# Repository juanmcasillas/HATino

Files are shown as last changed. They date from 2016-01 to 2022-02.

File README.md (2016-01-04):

# HATino
Head tracking using ARDUINO and BLUETOOTH reusing code from HATIRE, using GY-521 breakout board (MPU-6050) and HC-05 breakout board for
bluetooth communications. The system is powered by standard AA-batteries, so it's a complete standalone solution.

This project is aimed to create a head tracking system based on code released by FuraX49 for the HATIRE plugin for OpenTRACK.

OpenTRACK is an OpenSource project focused on head tracking for MSWindows, Linux and Apple OSX. 
Manages multiple tracking sources and support multiple outputs. See https://github.com/opentrack/opentrack
for more details.

HATino provides a full solution (hardware and software) for a head tracking system based on arduino,
using bluetooth as comunication layer, in order to avoid "wires". HATino is implemented on an
ARDUINO MICRO, with a custom PCB Board, using GY-521 IMU breakout board for gyro information, and
HC-05 bluetooth breakout board for communications. The project includes both hardware (schematics,
pcb HOW-TO info) and software (ARDUINO custom firmware and modifications, Bluetooth layer) in order
to get a complete, OpenSource system. The software is based on FuraX49' code, and some of the 
examples on i2clib for arduino.

Libraries:

I2Cdev			https://github.com/jrowberg/i2cdevlib.git

Wire			(included)

SoftwareSerial	(included)

For information on installing libraries, see: http://arduino.cc/en/Guide/Libraries

Based on hatire source code (by FuraX49):

http://sourceforge.net/projects/hatire/files/ARDUINO/MPU6050/HAT_100.ino/download

LocalFile                       GIT
-----------------------------------------------------------------------------------------
HAT_gy521_wip_bt.ino            HATino.ino

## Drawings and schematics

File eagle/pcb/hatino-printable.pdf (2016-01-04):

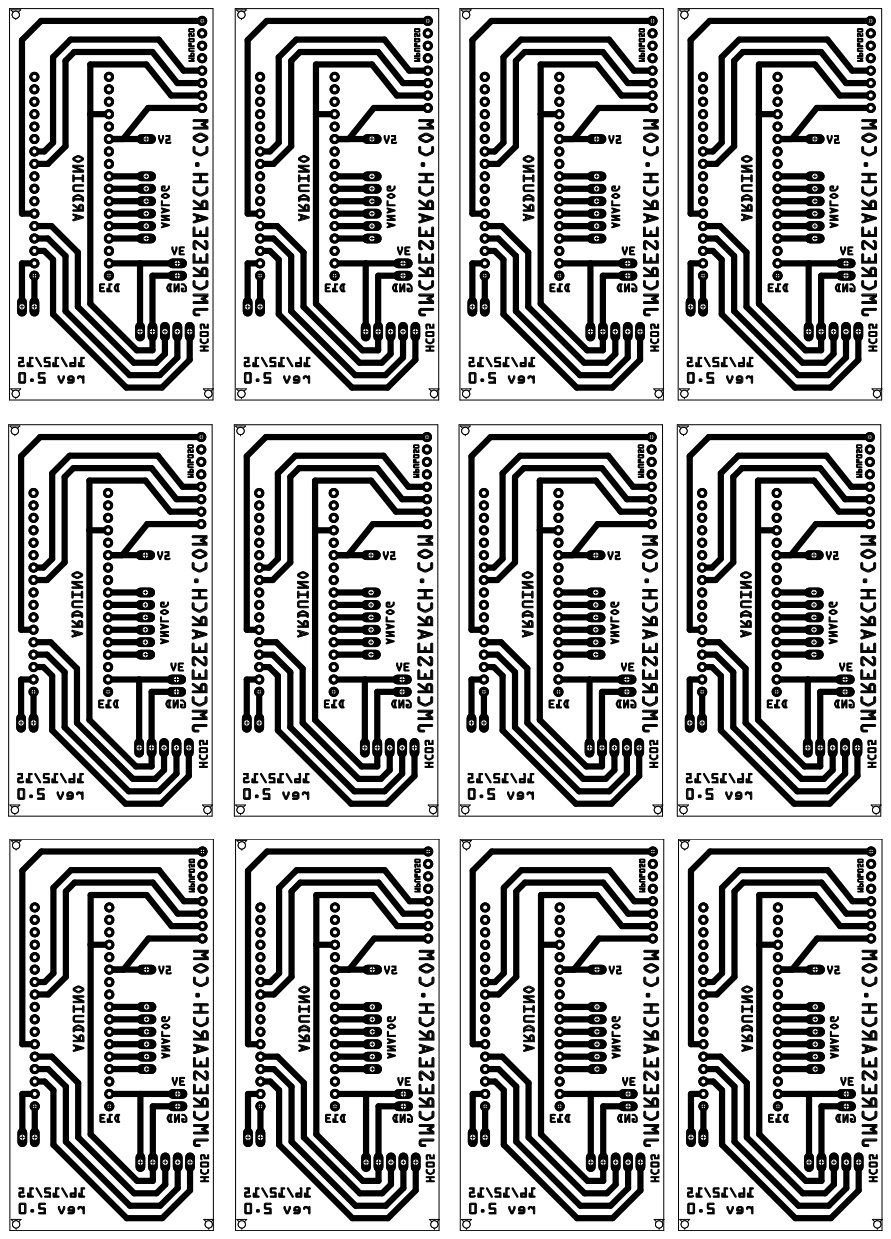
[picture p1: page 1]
JMCRESEARCH.COM; ANALOG; MPU6050; ARDUINO

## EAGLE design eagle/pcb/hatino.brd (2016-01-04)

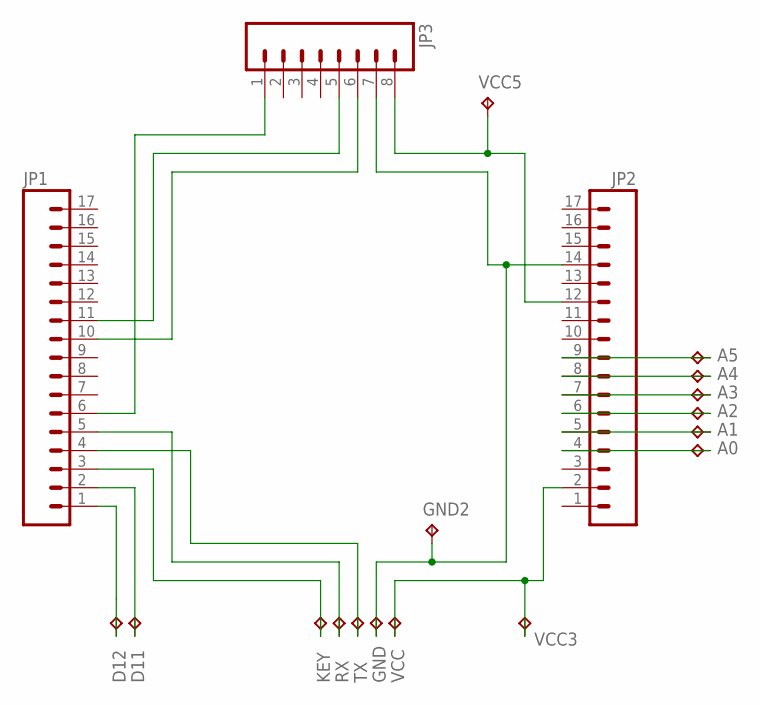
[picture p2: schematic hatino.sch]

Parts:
A0, A1, A2, A3, A4, A5: TPPAD1-13Y; P1-13Y
D11, D12: TPPAD1-13Y; P1-13Y
GND, GND2: TPPAD1-13Y; P1-13Y
JP1, JP2: M17; 1X17
JP3: M08; 1X08_ROUND
KEY: TPPAD1-13Y; P1-13Y
RX: TPPAD1-13Y; P1-13Y
TX: TPPAD1-13Y; P1-13Y
VCC, VCC3, VCC5: TPPAD1-13Y; P1-13Y

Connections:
unnamed: D12.TP, JP1.1
unnamed: JP2.2, VCC.TP, VCC3.TP
unnamed: D11.TP, JP1.2
unnamed: A0.TP, JP2.4
unnamed: A1.TP, JP2.5
unnamed: A2.TP, JP2.6
unnamed: A3.TP, JP2.7
unnamed: A4.TP, JP2.8
unnamed: A5.TP, JP2.9
unnamed: JP2.12, JP3.8, VCC5.TP
unnamed: GND.TP, GND2.TP, JP2.14, JP3.7
unnamed: JP1.5, RX.TP
unnamed: JP1.6, JP3.1
unnamed: JP1.4, TX.TP
unnamed: JP1.10, JP3.6
unnamed: JP1.11, JP3.5
unnamed: JP1.3, KEY.TP

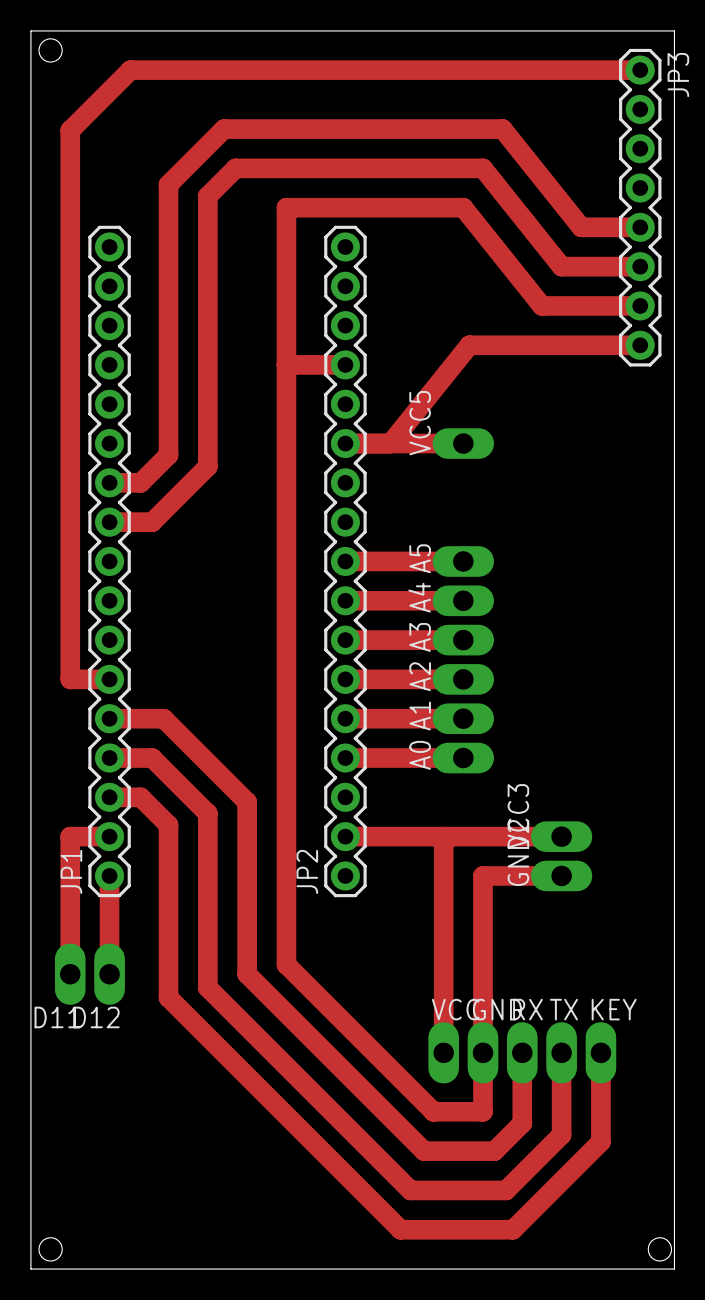
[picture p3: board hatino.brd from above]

Board: 2 copper layers, 41.6 x 80.0 mm, 19 parts (0 on the bottom side), 17 nets.

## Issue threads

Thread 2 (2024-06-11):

Opentrack doesn't recognise it.

OMaT8, 2024-06-11:
When i pair it on arduino and turn it on i recieve this message on serial monitor:
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

However when i pair it on opentrack nothing happens
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

The only thing i changed on the code was the bluetooth pairing to make it work with my hc-06 instead of the hc-05

Sorry if you are not working on this anymore but if you can help me with this i would be grateful.

Miningflo, 2024-12-30:
Hi, you're probably not looking at this anymore but I came across your post.
This might still help other people.

You haven't configured your arduino commands.
Digging around in the code I found following serial commands;
Start: S
Stop: s
Reset: R
Center: C

Other commands I couldn't immediately link:
V: looks like it just prints the version
I: dumps all the info in the Serial bus

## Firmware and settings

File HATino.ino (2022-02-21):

// Arduino sketch for MPU6050 on NanoWII using DMP MotionApps v4.1 
// HAT 14/04/2013 by FuraX49
//
// Head Arduino Tracker  for FaceTrackNoIR 
//   http://facetracknoir.sourceforge.net/home/default.htm	
// I2C device class (I2Cdev)
//   https://github.com/jrowberg/i2cdevlib
//
// Some fixes done by Juan M. Casillas <juan,.casillas@gmail.com>
// Code cleanup, Serial fixes and porting to Arduino Micro.
//
//          ARDUINOMICRO GY-521
//          -------------------------------
// PINOUT:  SDA (D2)      SDA
//          SCL (D3)      SCL
//          5V            VCC
//          GND           GND
//                        XDA Not connected
//                        XCL Not Connected
//                        ADO Not Connected (my board, low, i2c address 0x68. High, 0x69)
//                        INT Not Connected
// 
//  NO PULLOUT resistors in SDA, SCL
//


#include <avr/eeprom.h>
#include <Wire.h>
#include "I2Cdev.h"
#include "MPU6050_6Axis_MotionApps20.h"
#include <SoftwareSerial.h>

//#define DEBUG_JMC 1

#define BTSERIAL 1

MPU6050 mpu;
SoftwareSerial BTSerial(8, 9); // RX | TX

typedef struct  {
  int16_t  Begin  ;   // 2  Debut
  uint16_t Cpt ;      // 2  Compteur trame or Code info or error
  float    gyro[3];   // 12 [Y, P, R]    gyro
  float    acc[3];    // 12 [x, y, z]    Acc
  int16_t  End ;      // 2  Fin
} _hatire;

typedef struct  {
  int16_t  Begin  ;   // 2  Debut
  uint16_t Code ;     // 2  Code info
  char     Msg[24];   // 24 Message
  int16_t  End ;      // 2  Fin
} _msginfo;

typedef struct 
{
  byte   rate;
  double gyro_offset[3] ;
  double acc_offset[3]  ;
} _eprom_save;


// MPU control/status vars
bool dmpReady = false;  // set true if DMP init was successful
bool dmpLoaded = false;  // set true if DMP loaded  successfuly
uint8_t mpuIntStatus;   // holds actual interrupt status byte from MPU
uint8_t devStatus;      // return status after each device operation (0 = success, !0 = error)
uint16_t packetSize;    // expected DMP packet size (default is 42 bytes)
uint16_t fifoCount;     // count of all bytes currently in FIFO
uint8_t fifoBuffer[64]; // FIFO storage buffer

char Commande;
char Version[] = "HAT V 1.10";
const byte      INTERRUPT_PINNUMBER = 7;                    // where the INT is attached. Varies from Arduinos

// orientation/motion vars
Quaternion q;           // [w, x, y, z]         quaternion container
VectorInt16 aa;         // [x, y, z]            accel sensor measurements
VectorFloat gravity;    // [x, y, z]            gravity vector

float Rad2Deg = (180/M_PI) ;

// trame for message 
_hatire hatire;
_msginfo msginfo;
_eprom_save eprom_save;


bool   AskCalibrate = false;  // set true when calibrating is ask
int    CptCal =  0;
const int    NbCal = 5; 




// ================================================================
// ===               INTERRUPT DETECTION ROUTINE                ===
// ================================================================
volatile bool mpuInterrupt = false;     // indicates whether MPU interrupt pin has gone high

void dmpDataReady() {
  mpuInterrupt = true;
}

// ================================================================
// ===               PRINT SERIAL FORMATTE                      ===
// ================================================================
void PrintCodeSerial(uint16_t code,const char Msg[24],bool EOL ) {
  msginfo.Code=code;
  memset(msginfo.Msg,0x00,24);
  strcpy(msginfo.Msg,Msg);
  if (EOL) msginfo.Msg[23]=0x0A;
  // Send HATIRE message to  PC
  

#ifndef BTSERIAL
    Serial.write((byte*)&msginfo,30);
#else
    BTSerial.write((byte*)&msginfo,30);
  #endif
}


   
  
// ================================================================
// ===                      INITIAL SETUP                       ===
// ================================================================

void setup() {
  // join I2C bus (I2Cdev library doesn't do this automatically)
  Wire.begin();
  TWBR = 24;      
  // put the i2c bus at 200kHz to prevent buffer Overflow Don't work so much.
  // problems are related with the SERIAL port (to low)
  // try to write less packets.

  // initialize serial communication

#ifndef BTSERIAL
  Serial.begin(115200); // max speed supported by OpenTrack
  while (!Serial); // wait for Leonardo enumeration, others continue immediately
#else
  // BT INIT
  
  pinMode(10, OUTPUT);  // this pin will pull the HC-05 pin 34 (key pin) HIGH to switch module to AT mode
  // unconnect it or set it to low.
  digitalWrite(10, LOW);
  BTSerial.begin(115200);  // HC-05 default speed in AT command more
#endif  
  
  //Serial.begin(115200);
  //Serial.begin(230440); // runs smooth
  

  // From arduino manual
  // The default is 8 data bits, no parity, one stop bit.
  // baudrate:  115200
  // data bits: 8
  // parity:  None
  // stop bit: 1
  // Flow-Control:  None.
  
  
  
  
  
  PrintCodeSerial(2000,Version,true);

  hatire.Begin=0xAAAA;
  hatire.Cpt=0;
  hatire.End=0x5555;

  msginfo.Begin=0xAAAA;
  msginfo.Code=0;
  msginfo.End=0x5555;

  // initialize device
  PrintCodeSerial(3001,"Initializing I2C",true);
  mpu.initialize();

  // verify connection
  PrintCodeSerial(3002,"Testing connections",true);

  if (mpu.testConnection()){
     PrintCodeSerial(3003,"MPU6050 connection OK",true);
  } else {
     PrintCodeSerial(9007,"MPU6050 ERRROR CNX",true);
  }

  while (Serial.available() && Serial.read()); // empty buffer

  mpu.setFullScaleGyroRange(MPU6050_GYRO_FS_250);
  mpu.setFullScaleAccelRange(MPU6050_ACCEL_FS_2);
  // load and configure the DMP
  PrintCodeSerial(3004,"Initializing DMP...",true);
  devStatus = mpu.dmpInitialize();

  // JMC. Set the offsets for this thing (from MPU6050_DMP6 demo program)

  mpu.setXGyroOffset(220);
  mpu.setYGyroOffset(76);
  mpu.setZGyroOffset(-85);
  mpu.setZAccelOffset(1788); // 1688 factory default for my test chip


 
  // make sure it worked (returns 0 if so)
  if (devStatus == 0) {
    dmpLoaded=true;

    // Read Epprom saved params
    PrintCodeSerial(3005,"Reading saved params...",true);
    //ReadParams();

    mpu.setXGyroOffset(68);
    mpu.setYGyroOffset(-8); 
    mpu.setZGyroOffset(12);
    mpu.setXAccelOffset(-257); // 1688 factory default for my test chip
    mpu.setYAccelOffset(638); // 1688 factory default for my test chip
    mpu.setZAccelOffset(1220); // 1688 factory default for my test chip
    
    // turn on the DMP, now that it's ready
    PrintCodeSerial(3006,"Enabling DMP...",true);
    mpu.setDMPEnabled(true);

    // enable Arduino interrupt detection
    PrintCodeSerial(3007,"Enabling interrupt",true);
    // jmc ¿ what pin ? you should point to the required one
    // INT0 -> SCL in Micro. D3
    // INT1 -> SDA           D2 
    // INT2 -> TX (Serial)   RX1 
    // INT3 -> RX (Serial)   TX1
    // INT4 ??? 
     
    attachInterrupt(digitalPinToInterrupt(INTERRUPT_PINNUMBER), dmpDataReady, RISING);
    mpuIntStatus = mpu.getIntStatus();

    // set our DMP Ready flag so the main loop() function knows it's okay to use it
    PrintCodeSerial(5000,"HAT BEGIN",true);
    dmpReady = true;
    // get expected DMP packet size for later comparison
    packetSize = mpu.dmpGetFIFOPacketSize();    

    // JMC this is NOT in the example -- remove it
    // Empty FIFO
    /*
    fifoCount = mpu.getFIFOCount();  
    while (fifoCount > packetSize) {
      fifoCount = mpu.getFIFOCount();
      mpu.getFIFOBytes(fifoBuffer, fifoCount);
    }
    */
  } 
  else {
    // ERROR!
    // 1 = initial memory load failed
    // 2 = DMP configuration updates failed
    // (if it's going to break, usually the code will be 1)
    dmpLoaded=false;
    PrintCodeSerial(9000+devStatus,"DMP Initialization failed",true);
  }
}


// ================================================================
// ===                    RAZ OFFSET                            ===
// ================================================================
void razoffset() {
  eprom_save.gyro_offset[0] = 0;
  eprom_save.gyro_offset[1] = 0;
  eprom_save.gyro_offset[2] = 0;
  eprom_save.acc_offset[0] = 0;
  eprom_save.acc_offset[1] = 0;
  eprom_save.acc_offset[2] = 0;
}


// ================================================================
// ===                    SAVE PARAMS                           ===
// ================================================================
void SaveParams() {
  eeprom_write_block((const void*)&eprom_save, (void*) 0, sizeof(eprom_save));
}



// ================================================================
// ===                    READ PARAMS                           ===
// ================================================================
void ReadParams() {
  eeprom_read_block( (void*)&eprom_save, (void*) 0, sizeof(eprom_save));
}


// ================================================================
// ===                    Serial Command                        ===
// ================================================================
void serialEvent(){
  Commande = (char)Serial.read();
  switch (Commande) {
  case 'S':
    PrintCodeSerial(5001,"HAT START",true);
    if (dmpLoaded==true) {
      mpu.resetFIFO();   
      hatire.Cpt=0;              
      attachInterrupt(0, dmpDataReady, RISING);
      mpu.setDMPEnabled(true);
      dmpReady = true;
    } 
    else {
      PrintCodeSerial(9011,"Error DMP not loaded",true);
    }
    break;      

  case 's':
    PrintCodeSerial(5002,"HAT STOP",true);
    if (dmpReady==true) {
      mpu.setDMPEnabled(false);
      detachInterrupt(0);
      dmpReady = false;
    }
    break;      

  case 'R':
    PrintCodeSerial(5003,"HAT RESET",true);
    if (dmpLoaded==true) {
      mpu.setDMPEnabled(false);
      detachInterrupt(0);
      mpu.resetFIFO();   
      hatire.Cpt=0;              
      dmpReady = false;
      setup();
    } 
    else {
      PrintCodeSerial(9011,"Error DMP not loaded",true);
    }
    break;      


  case 'C':
    CptCal=0;
    razoffset();  
    AskCalibrate=true;
    break;      

  case 'V':
    PrintCodeSerial(2000,Version,true);
    break;      

  case 'I':
  	BTSerial.println();
  	BTSerial.print("Version : \t");
    BTSerial.println(Version);
    BTSerial.println("Gyroscopes offsets");
    for (int i=0; i <= 2; i++) {
  	  BTSerial.print(i);
  	  BTSerial.print(" : ");
    	BTSerial.print(eprom_save.gyro_offset[i]);
  	  BTSerial.println();
    }
    BTSerial.println("Accelerometers offsets");
    for (int i=0; i <= 2; i++) {
  	  BTSerial.print(i);
  	  BTSerial.print(" : ");
    	BTSerial.print(eprom_save.acc_offset[i]);
  	  BTSerial.println();
    }
    break;      


  default:
    break;
  }	
}


// ================================================================
// ===                    MAIN PROGRAM LOOP                     ===
// ================================================================
void loop() {
  // Leonardo BUG (simul Serial Event)
  if(Serial.available() > 0)  serialEvent();


  // if programming failed, don't try to do anything
  if (dmpReady)  { 


    while ((!mpuInterrupt) && (fifoCount < packetSize)) ;

    // reset interrupt flag and get INT_STATUS byte
    mpuInterrupt = false;
    mpuIntStatus = mpu.getIntStatus();

    // get current FIFO count
    fifoCount = mpu.getFIFOCount();

    // check for overflow (this should never happen unless our code is too inefficient)
    if ((mpuIntStatus & 0x10) || fifoCount == 1024) {
      // reset so we can continue cleanly
      mpu.resetFIFO();
      PrintCodeSerial(9010,"Overflow FIFO DMP",true);
      hatire.Cpt=0;

      // otherwise, check for DMP data ready interrupt (this should happen frequently)
    } 
    else if (mpuIntStatus & 0x02) {
      // wait for correct available data length, should be a VERY short wait
      while (fifoCount < packetSize) fifoCount = mpu.getFIFOCount();

      // read a packet from FIFO
      mpu.getFIFOBytes(fifoBuffer, packetSize);

      // track FIFO count here in case there is > 1 packet available
      // (this lets us immediately read more without waiting for an interrupt)
      fifoCount -= packetSize;

      // Get Euler angles in degrees
      mpu.dmpGetQuaternion(&q, fifoBuffer);
      mpu.dmpGetGravity(&gravity, &q);
      mpu.dmpGetYawPitchRoll(hatire.gyro, &q, &gravity);

 

      // Get real acceleration, adjusted to remove gravity
      // not used in this script
      // mpu.dmpGetAccel(&aa, fifoBuffer);
      // mpu.dmpGetLinearAccel(&hatire.acc, &aa, &gravity);

      // Calibration sur X mesures  
      if (AskCalibrate) {
        if ( CptCal>=NbCal) {
          CptCal=0;
          eprom_save.gyro_offset[0] = eprom_save.gyro_offset[0] / NbCal ;
          eprom_save.gyro_offset[1] = eprom_save.gyro_offset[1] / NbCal ;
          eprom_save.gyro_offset[2] = eprom_save.gyro_offset[2] / NbCal ;
          AskCalibrate=false;
          SaveParams();
        } 
        else {
          eprom_save.gyro_offset[0] += (float) hatire.gyro[0];
          eprom_save.gyro_offset[1] += (float) hatire.gyro[1];
          eprom_save.gyro_offset[2] += (float) hatire.gyro[2];

          CptCal++;
        }
      }



      // adjust board position. By default works if the GY-521 board is set flat (chip and led facing up)
      // and pin solders facing to right. far pin should be INT, near pin should be VCC. X Asis is the 
      // board plane, Y axis the perpendicular to it.
      
      // if you want rotate the board 90 ANTICLOCKWISE you should add + PI/2 angle to X (add it in degrees)

      // rotate 90 to LEFT (ANTICLOCWISE)

        hatire.gyro[0] += PI/2;


      // Conversion angles Euler en +-180 Degrees
      for (int i=0; i <= 2; i++) {
        hatire.gyro[i]= (hatire.gyro[i] - eprom_save.gyro_offset[i] ) * Rad2Deg;
        if  (hatire.gyro[i]>180) {
          hatire.gyro[i] = hatire.gyro[i] - 360;
        }
      }




      if (AskCalibrate) {
        hatire.gyro[0] = 0; 
        hatire.gyro[1] = 0;
        hatire.gyro[2] = 0;
        hatire.acc[0]= 0;
        hatire.acc[1] = 0;
        hatire.acc[2] = 0;
      }



      // Send Trame to HATIRE PC
      // DEBUG THE THING
#ifndef BTSERIAL
        Serial.write((byte*)&hatire,30);
#else
        BTSerial.write((byte*)&hatire,30);    
      #endif
      

      hatire.Cpt++;
      if (hatire.Cpt>999) {
        hatire.Cpt=0;
      }
    }
  }
  delay(1);
}

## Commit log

2016-01-04 Added PCB schematics for EAGLE. Added printable PDF file to create the PCB directly. Added EAGLE libraries
    [hatino.brd, hatino.sch]
2016-01-04 initial original source code HAT_100.ino from FuraX49. see:
    http://sourceforge.net/projects/hatire/files/ARDUINO/MPU6050/HAT_100.ino/download
    for original source code and more information.
2022-02-21 fixing the issue #1 opened by TSPitFire
    [HATino.ino]

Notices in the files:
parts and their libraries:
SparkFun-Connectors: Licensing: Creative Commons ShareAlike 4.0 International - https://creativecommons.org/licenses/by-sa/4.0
